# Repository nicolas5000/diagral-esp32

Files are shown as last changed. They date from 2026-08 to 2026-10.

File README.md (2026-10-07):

# diagral-uart-esp32
This project permits to connect to Diagral alarm system DIAG91AGFK using the 20 pins connector on the back (the connector used for the GSM board DIAG55AAX).

It permits to get status from and modify state of the alarm system as it could be done using call and SMS with official DIAG55AAX from Diagral, but using local MQTT connection... and it is directly recognized by Home Assistant!

This project is originally tested on XIAO-ESP32-S3 (with battery management by ESP32 board) and Waveshare ESP32-C6 (with battery management by the Diagral alarm system) hardware and based on ESP-IDF SDK version 6.0.2. It should also work with any other board compatible with Waveshare ESP32-S3 and ESP32-C6 board pinout.

This project is open source: you can reuse it and modify it, but please add a link to my project.
If you like this project you can [contribute](#how-to-contribute) or [buy me a coffee](https://buymeacoffee.com/nicolas5000) to support the tens of hours I spent on it :blush:.

### Why I did this project

From Diagral, DIAG55AAX (also known as DIAG55AAX1) is a 2G only mobile network board and DIAG55AAX5 is 2G/3G mobile network board. These boards will not work anymore in the future as the 2G and 3G mobile networks are being replaced by 4G and 5G networks. Of course you can buy the official Diagral 4G device to replace your old DIAG55AAX module.

The goal of this project is to connect your Diagral system locally to your Home Assistant without any Cloud based solution.

### **Disclaimer**  
> [!CAUTION]
> This tool is designed for educational and testing purposes, provided "as is", without warranty of any kind. It has no link with Diagral company. Creators and contributors are not responsible for any misuse or damage caused by this tool. Keep in mind that you should have a secure MQTT and Home Assistant instances to avoid any attack on your alarm system from your domotics.

### **Security**
To use this project in a secure way, you shall:
- Put the board on the back of the DIAG91AGFK so it is protected by your alarm system tamper mechanism.
- Put a password on command line access (at least in production, when not testing anymore).
- Use a secure network (Wifi password...).
- Use a secure MQTT connection (strong password, certificate...).
- Protect your Home Assistant access.
- If you want the best:
  - Sign your firmware and enable secure boot (see ESP-IDF documentation). This risk can be mitigated by using [HTTPS server for OTA update](#ota-over-https).
  - Enable flash encryption (see ESP-IDF documentation) to protect your Wifi password, command-line password and MQTT password. This risk is mitigated by putting the ESP32 on the back of the DIAG91AGFK (protected by your alarm system tamper mechanism).

### Documentation
This documentation contains useful information about the project, especially:
- [Hardware requirements](README.md#hardware-requirements) to use the project
- [Software configuration](doc/configuration.md) (hardware pins used, network and MQTT settings, ...)
- [Using command line](doc/command_line.md) to test and configure the project
- [MQTT topics and messages](doc/mqtt.md)
- [The project development](doc/development_guide.md) (structure of the project, how the source code is organized if you want to contribute or fork...)
- [The current knowledge about the protocol and commands](doc/protocol.md) used between DIAG91AGFK and DIAG55AAX

### Support
I try to give support on my free time. If you have questions you can open a subject and ask directly in English (for everyone to understand) or in French.

### Project status

These features are currently available:
- Get state from Diagral alarm system:
  - Mode (idle, setup, test)
  - Zones 1 to 4 status (disarmed, arming, armed, armed "home", triggered)
  - Battery charging state. Note: it works only if you have a battery connected to provide power to the device!
- Control the alarm system: Arm/"Arm home"/Disarm with or withour PIN code (choose before building firmware or from command line, can't be modified from MQTT and Home Assistant).
- Events:
  - Error event: event type (tamper, main power, battery, radio link, internet link, arm cancelled reason), harware type (system, sensor, command, siren), hardware number
  - Detection event: event type, sensor type, sensor number
  - Alert event: alert type (fire, alert, silent alert, duress disarm), command number
- Control the ESP32:
  - Reboot
  - Enable/disable logging
  - Enable/disable passive mode
- Connectivity:
  - Wifi (integrated to ESP32 chip) support
  - Ethernet support (based on W5500/WIZ850io module)
  - DHCP support, with DNS provided by DHCP server
  - Static IPv4 support, including manual DNS server configuration
- (S)NTP support for time synchronization (required to have valid timestamps in MQTT messages)
- Front-end:
  - Command line features: see [dedicated page](doc/command_line.md) for more information
    - Control the alarm system
    - Reboot ESP32
    - Change Wifi configuration without reflashing firmware (configuration applied after reboot)
    - Change DHCP/IPv4 configuration without reflashing firmware (configuration applied after reboot)
    - Change MQTT configuration without reflashing firmware (configuration applied after reboot)
    - Change Diagral configuration without reflashing firmware (configuration applied after reboot)
    - Note: command line features are password protected by default, change default password in project configuration before building firmware.
  - MQTT support: see [dedicated page](doc/mqtt.md) for more information
    - Discovery message is published and compatible with Home Assistant, permitting to automatically add device to it without extra configuration.
    - In addition:
      - A button is added to reboot the ESP32 board.
      - A switch is added to enable/disable Diagral layer logging (applied after reboot).
      - A switch is added to enable/disable Diagral passive mode (applied after reboot).
      - A text is added to provide URL of the new firmware for OTA (sending the text will start OTA).
- Configuration storage to flash
- [OTA firmware update](#ota-update) (update from Wifi or Ethernet using an HTTP(S) server) with rollback.
- MQTT connectivity watchdog: if MQTT connection is broken more than 5 minutes, the ESP32 will notify the alarm system and reboot.

### Diagral DIAG91AGFK 20-pins connector
The DIAG91AGFK has a 20-pins connector on the back to connect the DIAG55AAX GSM module. We use this connector for our project. Please check pin numbers:
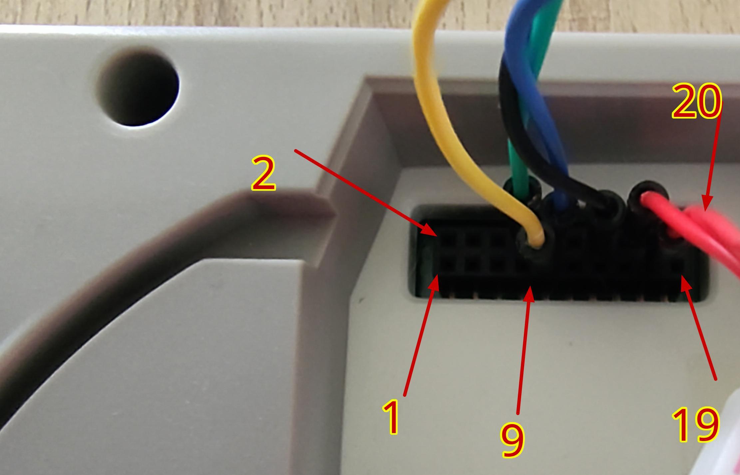
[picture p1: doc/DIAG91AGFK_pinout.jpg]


Here is the pin description for the connector:
| Pin # | Description | Used by the project? |
|----|---|---|
| 1 | Audio from DIAG91AGFK microphone, unknown format | No |
| 2 | Audio to DIAG91AGFK speaker, unknown format | No |
| 3 | Audio from DIAG91AGFK microphone, unknown format | No |
| 4 | Audio to DIAG91AGFK speaker, unknown format | No |
| 5 | GND | Yes (at least once) |
| 6 | GND | Yes (at least once) |
| 7 | Seems to be 2.8V (LVCMOS?) from DIAG91AGFK | No |
| 8 | RX for DIAG91AGFK / TX for DIAG55AAX and our project (0V at low state, 2.8V at high state) | Yes |
| 9 | "Signal" pin, low by default, set to 2.8V by DIAG91AGFK or DIAG55AAX a few ms before sending any command on corresponding TX (wake up?) | Yes |
| 10 | TX for DIAG91AGFK / RX for DIAG55AAX and our project (0V at low state, 2.8V at high state) | Yes |
| 11 | 3.3V from DIAG55AAX | No |
| 12 | Seems to be 2.8V (LVCMOS?) from DIAG91AGFK | No |
| 13 | GND | Yes (at least once) |
| 14 | GND | Yes (at least once) |
| 15 | GND | Yes (at least once) |
| 16 | Power from DIAG91AGFK | Yes (at least once) |
| 17 | +BATT from the project | Yes (at least once. If not using battery, use a 1N5819 to connect power from pin 16 or 18 to this pin) |
| 18 | Power from DIAG91AGFK | Yes (at least once) |
| 19 | +BATT from the project | Yes (at least once. If not using battery, use a 1N5819 to connect power from pin 16 or 18 to this pin) |
| 20 | +BATT from the project | Yes (at least once. If not using battery, use a 1N5819 to connect power from pin 16 or 18 to this pin) |

> [!NOTE]
> - It is not required to connect all GND pins as they are already connected together on DIAG91AGFK side. Connect your project board to at least 1 GND pin.
> - It is not required to connect all Power pins as they are already connected together on DIAG91AGFK side. Connect your project board to at least 1 power pin.
> - It is not required to connect all +BATT pins as they are already connected together on DIAG91AGFK side. Connect your project board to at least 1 +BATT pin.

### Hardware requirements
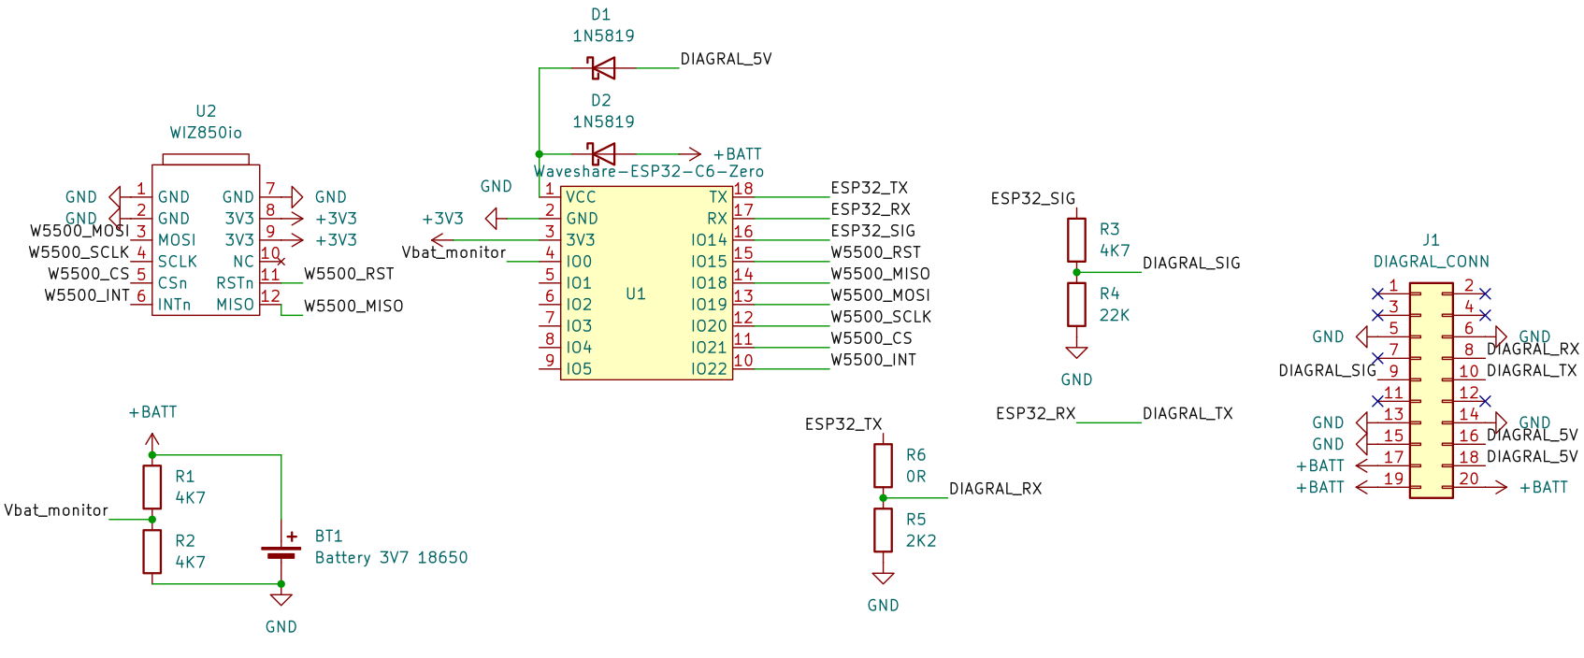
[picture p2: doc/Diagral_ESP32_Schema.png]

In order to use this project, you will need:
- ESP32 board:
  - For PCB "beta" and 1.0, use [Seeed Studio XIAO-ESP32-S3](https://www.amazon.fr/dp/B0BYSB66S5/).
  - For PCB 1.1, use Waveshare ESP32-C6 or ESP32-S3 (or from other provider, but with equivalent pinout).
- 5 or 6 resistors (see the schematics):
  - R1 and R2 are required only if you want to monitor battery voltage. You can choose any values but the voltage on the GPIO shall always remains under 3.3V! I chose to use the same resistors but it's not mandatory. You can modify min (0%) and max (100%) voltage values in the configuration.
  - R3 and R4 are always required as they permit to convert the voltage level between Diagral (2.8V) and ESP32 (3.3V) for "Signal" pin.
  - R5 and R6 are always required as they permit to convert the voltage level between Diagral (2.8V) and ESP32 (3.3V) for "ESP32 TX" pin. Please note that in my case R6 is not needed as the ESP32-S3 board from Seeed Studio and Waveshare already have a 499 ohm resistor internally.
- For PCB "beta" and 1.0, [XL74610](https://www.amazon.fr/dp/B0H2HY1DP9/) "ideal diode" if you plan to charge the battery from the DIAG91AGFK 5V power supply (in fact the DIAG91AGFK provides 4.5V and it is required to use at least 4.257V to fully charge a battery like 18650 that is 4.2V at 100%, so normal diode can't be used)
- 1 (PCB "beta" and 1.0) or 2 (PCB 1.1) 1N5819 diode(s).
- Wires:
  - To connect everything to the ESP32 board if you don't use a PCB.
  - To Replace R6 0 ohm resistor
  - On PCB "beta" and 1.0 only, to connect battery pins to XIAO back.
- USB cable to connect the ESP32 board to your computer for first flashing of the firmware.
- Battery (like 18650 battery, I didn't try to reuse the battery provided with the DIAG55AAX module but it could work) and its connector.
- [W5500](https://www.amazon.fr/dp/B0B775X737/) Ethernet module only if you don't want to use Wifi
- 20 pins connector to connect to DIAG91AGFK if you don't want to use "Dupont" wires on your final project board.

### PCB
I have created a [kicad](./kicad/) project for schematics and PCB routing. Current version of the PCB is 1.1.  
You can directly purchase a PCB (minimum order of 5 units) from PCBWay using this [link](https://www.pcbway.com/project/shareproject/diagral_esp32_gerber_d70e3251.html) or ask me for available PCB and passive components (I don't provide ESP32, W5500 and battery and I don't solder the components). 
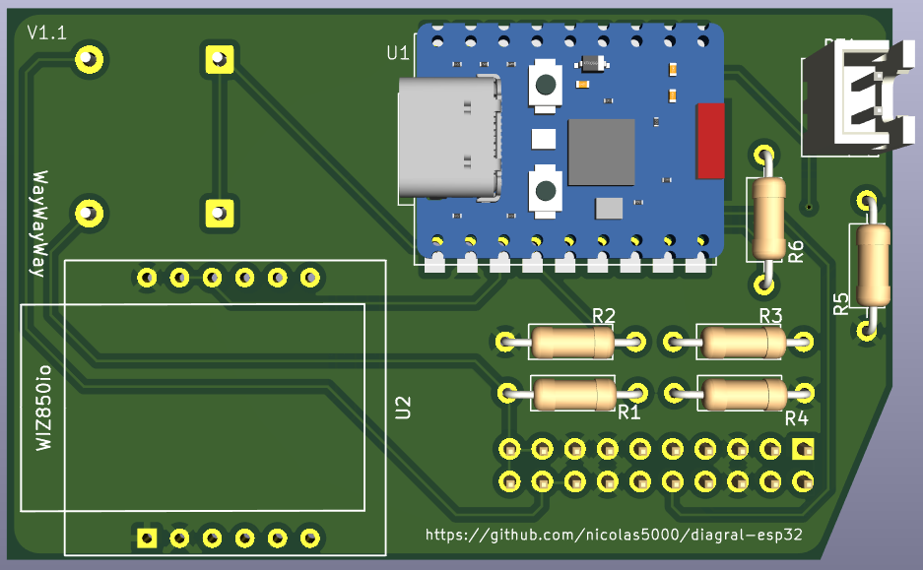
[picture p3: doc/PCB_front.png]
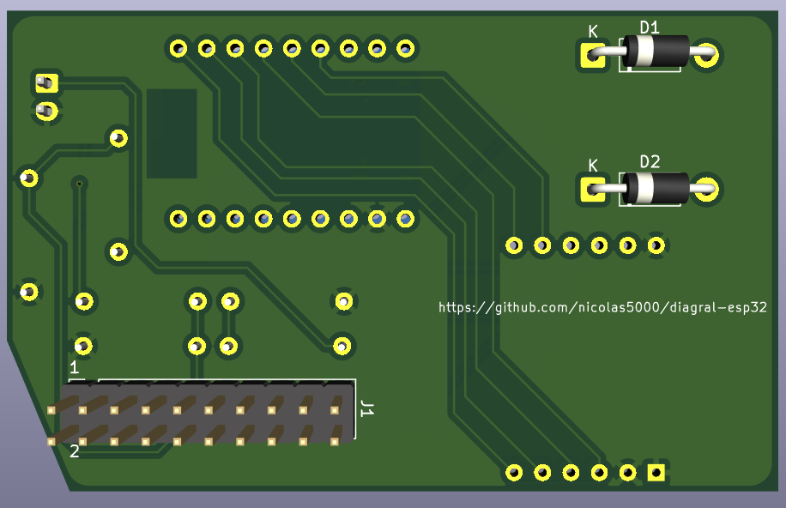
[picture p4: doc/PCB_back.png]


> [!CAUTION]
> Please note that mounting the W5500 module to use the Ethernet link will require to cut the back of the DIAG91AGFK because the W5500 is too big as you can see:
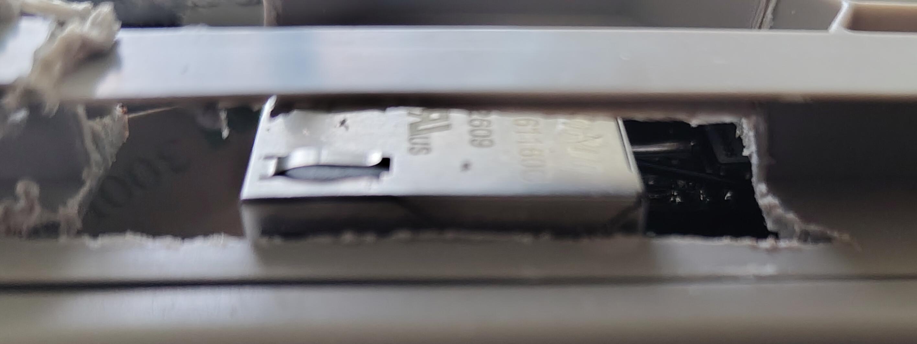
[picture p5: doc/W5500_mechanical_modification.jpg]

#### PCB versions

| PCB # | ESP32 compatibility | Limitations |
|----|---|---|
| beta | [Seeed Studio XIAO-ESP32-S3](https://www.amazon.fr/dp/B0BYSB66S5/) | (1) (2) |
| 1.0 | [Seeed Studio XIAO-ESP32-S3](https://www.amazon.fr/dp/B0BYSB66S5/) | (2) |
| 1.1 | Waveshare [ESP32-C6-Zero](https://amzn.eu/d/0iYieorw) or [ESP32-S3-Zero](https://amzn.eu/d/05cgIHxE) (or equivalent pinout and footprint) | No known limitation |

Known limitations:
- (1) Ethernet module is not working on this PCB due to footprint error. Use this PCB only for Wifi project.
- (2) The 1N5819 is missing on this PCB. You have to cut the track between R1 and pin 19 of the connector and put the 1N5819 as shown on the schematics below (D2):
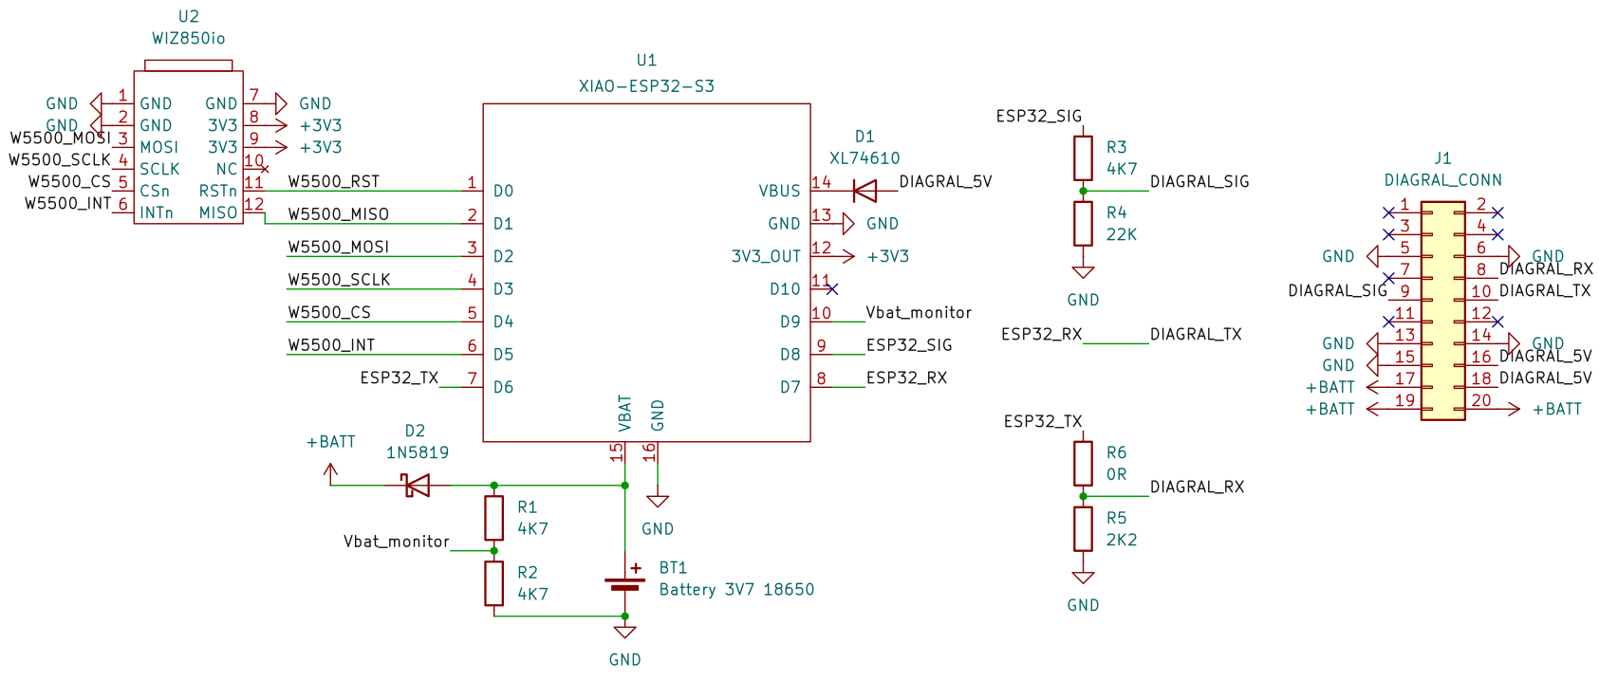
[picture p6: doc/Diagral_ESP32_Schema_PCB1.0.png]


#### Available PCB from France

| PCB # | PCB price | Passive components (optional) | Quantity available |
|----|---|---|---|
| beta | 3€ | 2€ for 20-pin connector, 1x 1N5819, 1x XL74610, 3x 4.7k resistors, 1x 22k resistor, 1x 2.2k resistor | 3 (in stock) |
| 1.0 | 3€ | 2€ for 20-pin connector, 1x 1N5819, 1x XL74610, 3x 4.7k resistors, 1x 22k resistor, 1x 2.2k resistor | 4 (in stock) |
| 1.1 | 5€ | 1€ for 20-pin connector, 2x 1N5819, 3x 4.7k resistors, 1x 22k resistor, 1x 2.2k resistor | on demand |

Additional costs for packaging and shipping to France (bubble envelope with tracking number) : 4€

> [!NOTE]
> Not included: ESP32, W5500 Ethernet module, battery and its connector, soldering the components on the PCB.

Here is an example of components on PCB 1.0:
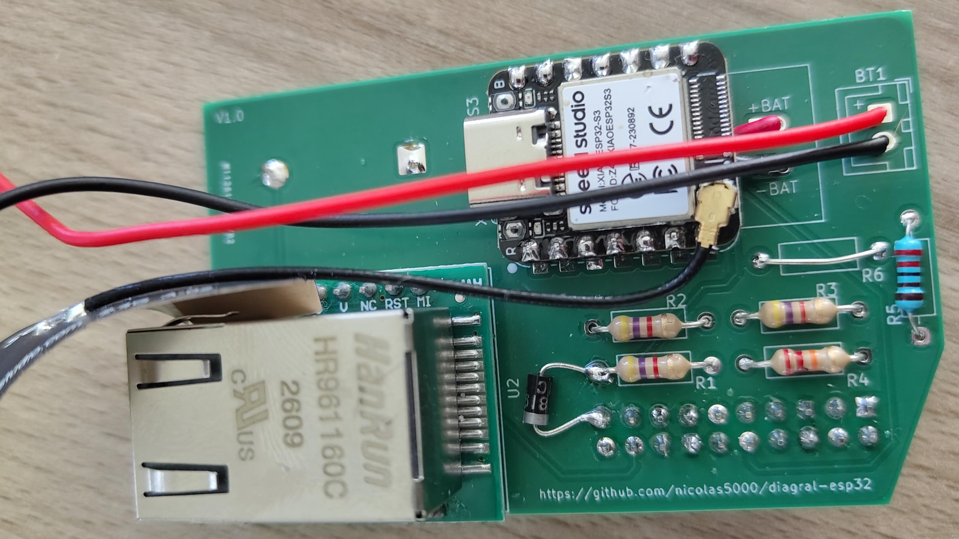
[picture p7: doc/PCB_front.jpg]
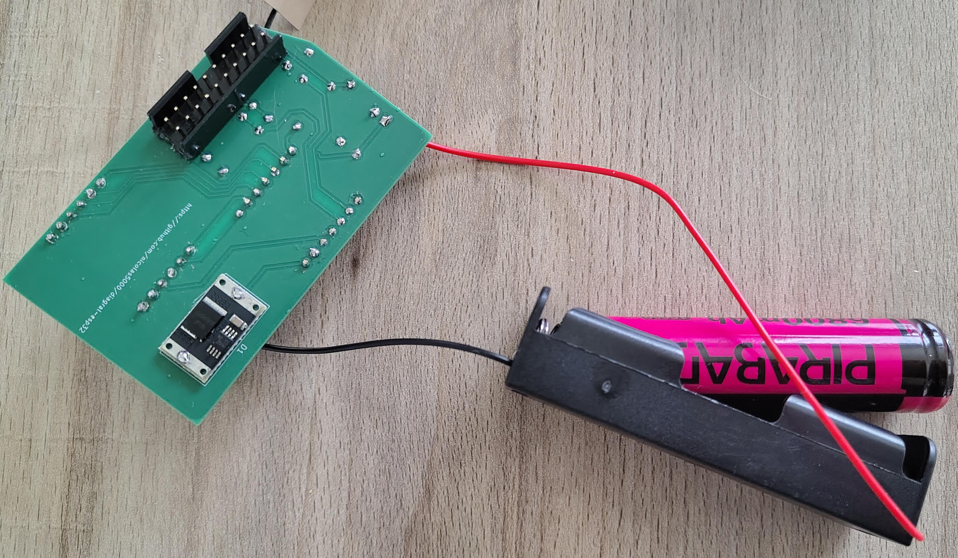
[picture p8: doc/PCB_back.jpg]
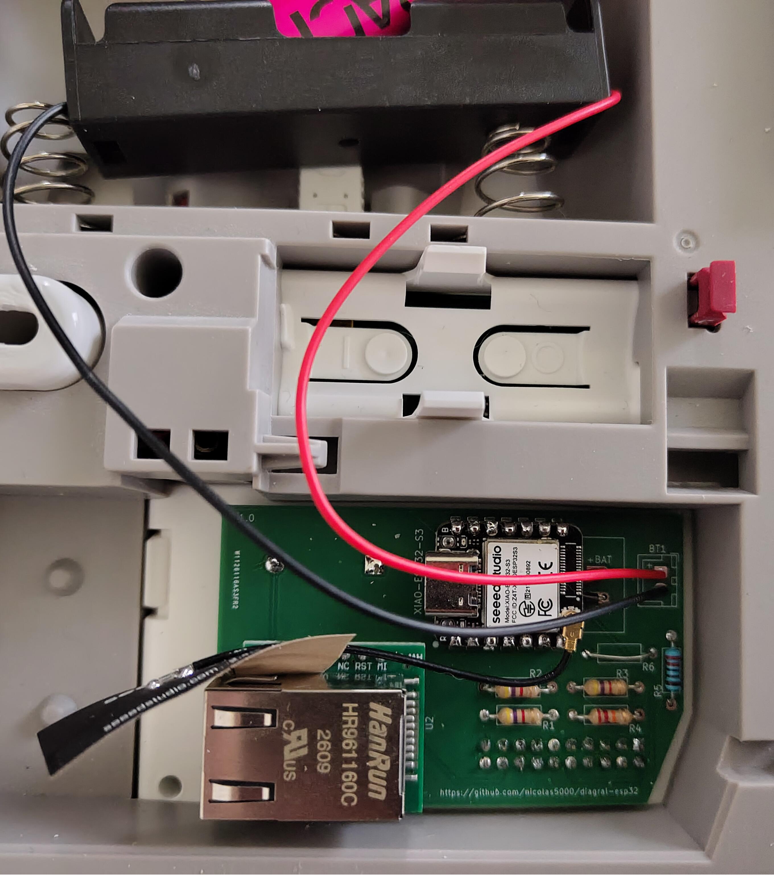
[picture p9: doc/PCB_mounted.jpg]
  

### Development environment

The development environment is based on:
- Visual Studio Code (also known as VSCode)
- ESP-IDF extension for VSCode and ESP-IDF SDK installed

### Starting guide

Here are a few steps to follow to start with this project:
1. If you are not familiar with VSCode and ESP-IDF, I encourage you to read ESP-IDF starting guide and try the "Hello world" example on your ESP32 board. You should be able to build the example, flash the binary to your ESP32 board and monitor the execution from ESP-IDF monitor tool before going to next step.
2. Download this project / clone the repository, then open the project folder in VSCode.
3. Solder the components on the PCB or use wires to connect all the pins on your prototyping board (see schematics above).
4. Copy and rename the sdkconfig.defaults_xxx file to sdkconfig.defaults depending on your hardware.
5. Choose the ESP32-S3 or ESP32-C6 target depending on your hardware.
6. Open "SDK Configuration Editor" to configure the project and go to "Diagral UART Project Configuration" section. Configure network and choose the GPIO pins you want to use to connect everything.
7. Provide your HTTPS public certificate for OTA (see [OTA section](#ota-update) to generate a certificate) or create an empty file named _ca_cert.pem_
8. Build the source code, flash it to the board and monitor (there is single button that does everything if you are confident, otherwise, use the 3 buttons in this order).

By default the project is configured with verbose enabled and not in passive mode: you can see what happens with detailed logs and you can control your Diagral alarm system. In active mode you can use the command line to send commands to your Diagral system. You can use passive mode to get frames from DIAG91AGFK to DIAG55AAX only (but you have to connect all 20 pins).

#### Passive mode

As previously explained, in passive mode (don't forget to enable verbose) you will get frames from DIAG91AGFK to DIAG55AAX only.
If you need to see all exchanges you will have to use another "spy UART project".

#### Active mode

In this mode you can control your alarm system.

> [!NOTE]
> Keep verbose enabled if you want to see what happens in Diagral UART layer. In addition to console, exchanged frames can be sent to a Syslog server.

### OTA update
In order to update the firmware from Wifi or Ethernet securely, you should use an HTTPS server. If you don't mind, you can also use a simple HTTP server. This section describes the 2 options.

> [!NOTE]
> After OTA is performed, the ESP32 will reboot automatically. Then, if MQTT is not able to connect within 60s, the rollback will be performed to reboot on previous firmware.

#### OTA over HTTPS
1. Generate your certificate and key: you can use the command `openssl req -x509 -newkey rsa:2048 -keyout ca_key.pem -out ca_cert.pem -days 365 -nodes`. Don't forget to use a CN field that matches the machine IP address or name (like _myserver.lan_) that will be used in the URL when performing OTA. Note: this file is required to build and be included within the first firmware to load using USB.
2. Open the update port in your firewall
3. Launch the HTTPS server. You can use the command `python3 simple_ota_https_server.py <BIN_DIR> <PORT> [CERT_DIR]` (simple_ota_https_server.py is in the tools folder)
4. From Home Assistant, enter the URL of the .bin file: `https://myserver.lan:8070/diagral-uart-esp32.bin` assuming you are using port 8070 on machine myserver.lan
5. Wait a few time (upgrade should be done in less than 30 seconds)

#### OTA over HTTP
1. Create an empty file named ca_cert.pem and disable option _Allow OTA update only over HTTPS_ in the project configuration before building the firmware
2. Open the update port in your firewall
3. Launch the HTTP server. You can use the command `python3 -m http.server 8070 --bind ::` in the build folder containing diagral-uart-esp32.bin
4. From Home Assistant, enter the URL of the .bin file: `http://myserver.lan:8070/diagral-uart-esp32.bin` assuming you are using port 8070 on machine myserver.lan
5. Wait a few time (upgrade should be done in less than 30 seconds)

### Home Assistant integration
The board will be automatically discovered by Home Assistant MQTT integration and provide controls (with control panel for all zones and for each zone), PIN code verification (if enabled in the configuration), events (detection, alert, error), diagnostics and OTA firmware update.
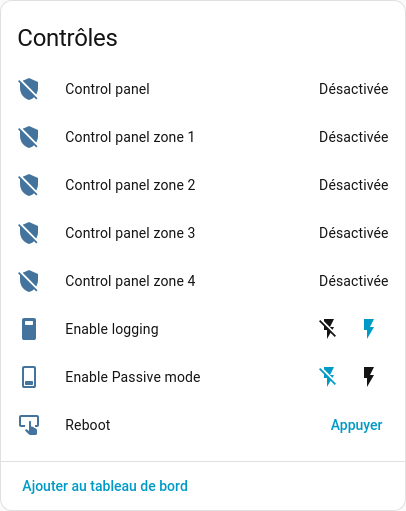
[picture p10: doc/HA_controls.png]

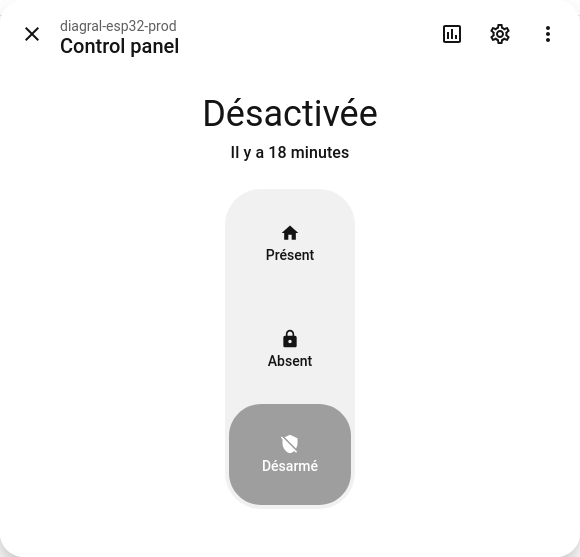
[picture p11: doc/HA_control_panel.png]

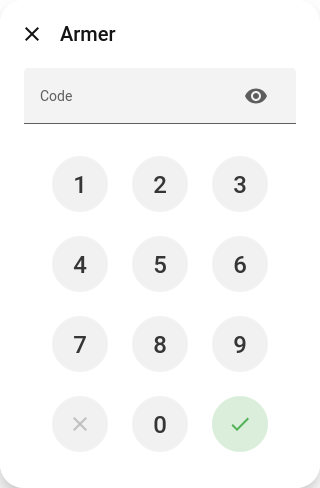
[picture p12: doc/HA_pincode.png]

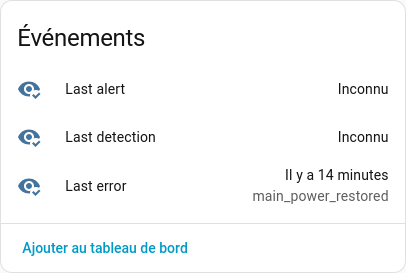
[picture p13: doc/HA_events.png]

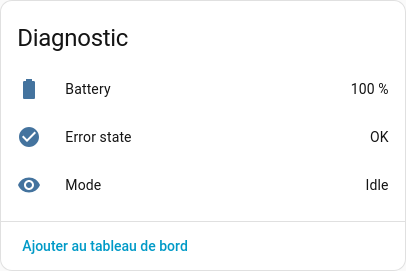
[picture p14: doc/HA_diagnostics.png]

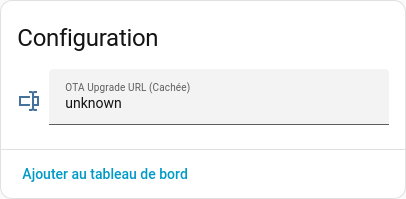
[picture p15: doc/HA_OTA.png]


### How to contribute

You can mainly contribute to this project by:
- Testing this project on your DIAG91AGFK alarm system and reporting any issue.
- If you have development skills you can propose source code modification to fix issues.
- [Buy me a coffee](https://buymeacoffee.com/nicolas5000).

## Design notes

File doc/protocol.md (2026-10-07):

# Communication protocol between DIAG91AGFK alarm system and DIAG55AAX GSM module
This page describes most of the protocol used between DIAG91AGFK alarm system and DIAG55AAX GSM module... at least useful commands to control and monitor the alarm system from this UART link.

## Hardware

### Pinout
As described in [Diagral DIAG91AGFK 20-pins connector](../README.md#diagral-diag91agfk-20-pins-connector), the 3 pins to control and monitor the alarm system are:
- Pin 8: UART RX for DIAG91AGFK / TX for DIAG55AAX
- Pin 9: "Signal" pin, low by default, set to 2.8V by DIAG91AGFK or DIAG55AAX a few ms before sending any command on corresponding TX (wake up?)
- Pin 10: UART TX for DIAG91AGFK / RX for DIAG55AAX

### UART
The UART characteritics are 115200 bps, 8 bits of data, no parity bit, 1 stop bit.

## Protocol

### Frame format

The format of each frame is:
| Byte # | Description |
|----|---|
| 0 | L = Length of the frame (this byte excluded) |
| 1 | Frame counter, from 0x00 to 0xFF, independent and incremented by each side (one for DIAG91AGFK, one for DIAG55AAX/ESP32) |
| 2 | I = Identifier of the frame |
| ... | ... |
| L | Checksum (XOR of all previous bytes, byte 0 included) |

> [!NOTE]
> In the following of this document, the frame length (byte 0), frame counter (byte 1) and checksum (last byte) will not always be shown for easy reading, however they are always present in the frames.

### Frame description

#### I=0x40 - ACK
All frames sent from one side must be acknowledged by the other side by sending this frame:
| Byte # | Description |
|----|---|
| 0 | L = Length of the frame (this byte excluded) = 0x04 |
| 1 | Frame counter of the frame to acknowledge |
| 2 | I = 0x40 |
| 3 | 0x01 (OK) |
| 4 | Checksum (XOR of all previous bytes, byte 0 included) |

#### I=0x04 - Commands to manage audio or binary blobs
> [!NOTE]
> This project doesn't use these audio or binary blobs, however we need to at least reply correctly to the frames from the alarm system.

| Byte # | Description |
|----|---|
| 0 | L = Length of the frame (this byte excluded) |
| 1 | Frame counter |
| 2 | I = Identifier of the frame |
| 3 | Always 0x20 |
| 4 | J Sub-command (see below) |
| ... | ... |
| L | Checksum (XOR of all previous bytes, byte 0 included) |

##### J=0x01 - Description of an audio or binary blob
This frame is used to describe an audio or binary blob, before transmitting the fragments.
| Byte # | Description |
|----|---|
| 2 | I = 0x04 |
| 3 | Always 0x20 |
| 4 | J = 0x01 |
| 5-11 | TBD |
| 12-13 | Total length of the audio or binary blob in bytes, MSB first |
| 14-15 | Maximum supported length of a segment in bytes, MSB first |

##### J=0x02 - Length of a segment (response to J=0x01)
This frame is a response to [J=0x01](#j0x01---description-of-an-audio-or-binary-blob), it contains the maximum supported length of a segment from the other side.
| Byte # | Description |
|----|---|
| 2 | I = 0x04 |
| 3 | Always 0x20 |
| 4 | J = 0x02 |
| 5-6 | Maximum supported length of a segment in bytes, MSB first |
| 7 | 0x00 - Only sent by the GSM module to accept the [J=0x01](#j0x01---description-of-an-audio-or-binary-blob) command to write the blob |

##### J=0x03 - Transmission of a fragment
This frame permits to transmit a fragment of a blob (part of the welcome message, personalized message for a sensor, ...)
| Byte # | Description |
|----|---|
| 2 | I = 0x04 |
| 3 | Always 0x20 |
| 4 | J = 0x03 |
| 5-6 | Fragment #, MSB first, strating from 1 |
| 7-8 | L = Length of the segment in bytes, MSB first |
| ... | Value (L bytes) |

##### J=0x04 - End of transmission of an audio or binary blob (after last J=0x03)
After sending all the fragments with [J=0x03](#j0x03---transmission-of-a-fragment), the sender emits this frame.
| Byte # | Description |
|----|---|
| 2 | I = 0x04 |
| 3 | Always 0x20 |
| 4 | J = 0x04 |

##### J=0x08 - Request to send an audio or binary blob
This frame is sent by the alarm system to the GSM module to read / extract a blob.
| Byte # | Description |
|----|---|
| 2 | I = 0x04 |
| 3 | Always 0x20 |
| 4 | J = 0x08 |
| 5-10 | TBD, same bytes as bytes 5-10 from [J=0x01](#j0x01---description-of-an-audio-or-binary-blob) |

##### J=0x09 - ACK of a segment (response to J=0x03)
This frame is sent to acknowldge each [fragment received](#j0x03---transmission-of-a-fragment).
| Byte # | Description |
|----|---|
| 2 | I = 0x04 |
| 3 | Always 0x20 |
| 4 | J = 0x09 |
| 5-6 | fragment # to acknowledge |

#### I=0x07 - Main commands
This section contains all the other commands to control and get status and notifications from the alarm system.
| Byte # | Description |
|----|---|
| 0 | L = Length of the frame (this byte excluded) |
| 1 | Frame counter |
| 2 | I = 0x07 |
| 3 | J Sub-command (see below) |
| ... | ... |

##### J=0x60 - Command to change the alarm system state
This frame is sent by the GSM module to get or change the alarm system state. The request contains 11 data bytes, so byte 0 (L) is 0x0D.
| Byte # | Description |
|----|---|
| 2 | I = 0x07 |
| 3 | J = 0x60 |
| 4 | 0x00 |
| 5 | Operation code (see below) |
| 6-12 | Reserved bytes and zone masks, depending on the operation |

The operation codes are:
| Value | Operation | Zone bytes |
|----|----|----|
| 0x10 | Disarm all zones | Bytes 6-7 = 0xFF |
| 0x11 | Arm all zones | Bytes 8-9 = 0xFF |
| 0x12 | Arm or disarm selected zones | Byte 7 = zones to disarm; byte 9 = zones to arm |
| 0x13 | Arm the home zones | No zone mask |
| 0x30 | Get the current state | No zone mask |

Zone masks use one bit per zone: 0x01 = zone 1, 0x02 = zone 2, 0x04 = zone 3, and 0x08 = zone 4. 0xFF can be used to select all zones.

A successful command is normally acknowledged with a miscellaneous response (K=0x28) and a status of 0x01. After that, the alarm system then returns a [J=0x62 status notification](#j0x62---status-notification-from-the-alarm-system), or refuses the change with [K=0x49](#k0x49---state-change-refused).
##### J=0x62 - Status notification from the alarm system
This notification is sent by the alarm system when its state changes. It can also be returned in response to a [J=0x60 state request](#j0x60---command-to-change-the-alarm-system-state). The payload contains 18 data bytes, so byte 0 (L) is 0x12.
| Byte # | Description |
|----|---|
| 2 | I = 0x07 |
| 3 | J = 0x62 |
| 4 | System mode: 0x00 = idle, 0x40 = test, 0x80 = setup |
| 5 | State flags (see below) |
| 6 | Error flags (see below) |
| 7 | Not interpreted by this project |
| 8 | Zone mask used when the system is disarmed |
| 9 | Not interpreted by this project |
| 10 | Zone mask used when the system is armed or arming |
| 11-17 | Not interpreted by this project |

The state flags in byte 5 use the following bits:
| Bit | Value | Meaning |
|----|----|----|
| 0 | 0x01 | Response to a state request |
| 1 | 0x02 | Home mode is active |
| 4 | 0x10 | Partial arm is active |
| 6 | 0x40 | Full arm is active |
| 7 | 0x80 | The system is arming |

The error flags in byte 6 can have the following values:
| Value | Meaning |
|----|----|
| 0x02 | Error (power lost, tamper, radio...) |
| 0x21 | Arm cancelled due to open issue |
| 0x22 | Arm cancelled due to transmitter error |
| 0x23 | Arm cancelled due to tamper |

The zone masks in bytes 8 and 10 use the same bit assignment as the [J=0x60 command](#j0x60---command-to-change-the-alarm-system-state).
##### J=0x65 - Alert notification from the alarm system
This notification is sent by the alarm system when an alert is triggered. The payload contains 13 data bytes, so byte 0 (L) is 0x0D.
| Byte # | Description |
|----|---|
| 2 | I = 0x07 |
| 3 | J = 0x65 |
| 4 | Not interpreted by this project |
| 5 | Alert type: 0x40 = fire, 0x50 = alert, 0x51 = silent alert, 0x53 = duress disarm alert |
| 6-8 | Not interpreted by this project |
| 9 | Number of the command that triggered the alert |
| 10+ | Not interpreted by this project |

The ESP32 records the alert type, command number, and reception time. No application-level response is required; the frame is acknowledged at the protocol link layer.
##### J=0x68 - Detection notification from the alarm system
This notification is sent by the alarm system when a sensor event occurs. The payload contains 13 data bytes, so byte 0 (L) is 0x0D.
| Byte # | Description |
|----|---|
| 2 | I = 0x07 |
| 3 | J = 0x68 |
| 4 | Not interpreted by this project |
| 5 | Detection event type (see below) |
| 6 | Zone mask for the affected zones |
| 7-9 | Not interpreted by this project |
| 10 | Sensor type: 0x00 = timeout, 0x01 = movement, 0x02 = opening |
| 11 | Sensor number |
| 12+ | Not interpreted by this project |

The known event types are:
| Value | Event |
|----|----|
| 0x07 | Dissuasion |
| 0x08 | Pre-alarm |
| 0x09 | Caution |
| 0x0A | Intrusion |
| 0x0B | Timer started |
| 0x0C | Timer ended |
| 0x18 | Pre-alarm confirmed |
| 0x1A | Intrusion confirmed |

The zone mask uses bit 0 for zone 1, bit 1 for zone 2, bit 2 for zone 3, and bit 3 for zone 4. The ESP32 marks the corresponding zones as triggered and records the event type, sensor type, sensor number, and reception time.
##### J=0x69 - GSM connectivity notification
This frame is sent by the GSM module to notify connectivity status. The payload contains 6 data bytes, so byte 0 (L) is 0x06.
| Byte # | Description |
|----|---|
| 2 | I = 0x07 |
| 3 | J = 0x69 |
| 4 | 0x01 in case of connectivity error, 0x00 otherwise |
| 5 | 0x55 = Connectivity status |
##### J=0x6B - Error notification from the alarm system
This notification is sent by the alarm system when an error or fault is raised or cleared. The payload contains 12 data bytes, so byte 0 (L) is 0x0C.
| Byte # | Description |
|----|---|
| 2 | I = 0x07 |
| 3 | J = 0x6B |
| 4 | System mode: 0x00 = idle, 0x40 = test, 0x80 = setup |
| 5 | Error state: 0x00 = cleared/restored, non-zero = active |
| 6 | Error type (see below) |
| 7 | Hardware type (see below) |
| 8 | Not interpreted by this project, seems to be always 0x00 |
| 9 | Hardware number |
| 10 | Not interpreted by this project, seems to be always 0x00 |
| 11 | Zone the sensor is part of, if error type is 'Radio link lost' and hardware type is 'sensor' |

The known error types are:
| Value | Meaning when active | Meaning when byte 5 is 0x00 |
|----|----|----|
| 0x40 | Tamper active | Tamper cleared |
| 0x55 | GSM or Internet link lost | GSM or Internet link restored |
| 0x59 | Radio link lost | Radio link restored |
| 0x70 | Battery low | Battery restored |
| 0x71 | GSM battery low | GSM battery restored |

The known hardware types are:
| Value | Hardware |
|----|----|
| 0x10 or 0x14 | Alarm system |
| 0x20 | Command module |
| 0x30 or 0x31 | Sensor |
| 0x40 | Siren |
| 0x50 | Internet transmitter |

The ESP32 records the error state, hardware type, hardware number, and reception time. Main power events are reported separately with [K=0x42](#k0x42---alarm-system-power-notification).
##### J=0x6C - State change ack
This frame is sent by the GSM module when the alarm system mode changes (in response to [J=0x62](#j0x62---status-notification-from-the-alarm-system)). The payload contains 6 data bytes, so byte 0 (L) is 0x06.
| Byte # | Description |
|----|---|
| 2 | I = 0x07 |
| 3 | J = 0x6C |
| 4 | 0x80 if alarm system in idle mode, 0x00 otherwise |
| 5 | 0x00 Unknown |
##### J=0x71 - PIN code management
This command family is used to read the configured PIN length and check a PIN code before sending a state-changing command.
###### K=0x09 - Request for PIN code length
This frame is sent by the GSM module to request the length of the PIN code.
| Byte # | Description |
|----|---|
| 2 | I = 0x07 |
| 3 | J = 0x71 |
| 4 | K = 0x09 |
###### K=0x0A - PIN code length response
This frame is returned by the alarm system in response to K=0x09.
| Byte # | Description |
|----|---|
| 2 | I = 0x07 |
| 3 | J = 0x71 |
| 4 | K = 0x0A |
| 5 | PIN code length in digits |
###### K=0x0B - Request for PIN code check
This frame is sent by the GSM module to check a PIN code. The PIN is encoded as BCD, with two decimal digits per byte and the first digit in the high nibble. The protocol supports up to six digits and pads an unused final byte with 0x00.
| Byte # | Description |
|----|---|
| 2 | I = 0x07 |
| 3 | J = 0x71 |
| 4 | K = 0x0B |
| 5 | PIN digits 1 and 2 |
| 6 | PIN digits 3 and 4 |
| 7 | PIN digits 5 and 6 |

For example, PIN `1234` is encoded as `0x12 0x34 0x00`. The input must contain decimal digits only.
###### K=0x0C - PIN code check status
This frame is returned by the alarm system in response to K=0x0B.
| Byte # | Description |
|----|---|
| 2 | I = 0x07 |
| 3 | J = 0x71 |
| 4 | K = 0x0C |
| 5 | 0x00 = PIN accepted; any other value = PIN rejected |
##### J=0x95 - Unknown from alarm system
This frame is sent by the alarm system during startup or power-on. Its payload is not interpreted by this project, but the frame requires a response from the GSM module.
| Byte # | Description |
|----|---|
| 2 | I = 0x07 |
| 3 | J = 0x95 |
| 4+ | Startup or power-on payload, not decoded |
##### J=0x96 - Unknown from GSM module
This is the response sent by the GSM module to a [J=0x95 frame](#j0x95---unknown-from-alarm-system). The following payload is an observed response that is reused in this project; the meaning of its individual bytes has not been determined.
| Byte # | Description |
|----|---|
| 2 | I = 0x07 |
| 3 | J = 0x96 |
| 4 | 0x81 |
| 5 | 0x02 |
| 6 | 0x0A |
| 7 | 0x26 |
| 8 | 0x6E |
| 9 | 0x24 |
| 10 | 0x01 |
| 11 | 0x90 |
| 12 | 0x31 |
| 13 | 0x01 |
| 14 | 0x01 |
| 15 | 0x00 |
| 16 | 0x00 |
##### J=0xB0 - Misc commands
This section contains miscellaneous commands and notifications.
###### K=0x10 - Language
This notification is sent by the alarm system to report its language.
| Byte # | Description |
|----|---|
| 2 | I = 0x07 |
| 3 | J = 0xB0 |
| 4 | K = 0x10 |
| 5 | Not interpreted by this project |
| 6 | Language code: 0x00 = French, 0x01 = Italian, 0x02 = German, 0x03 = Spanish, 0x04 = Dutch, 0x05 = English |
###### K=0x28 - Command validation response
This frame is sent by the alarm system or by the GSM module in response to some commands to be validated.
| Byte # | Description |
|----|---|
| 2 | I = 0x07 |
| 3 | J = 0xB0 |
| 4 | K = 0x28 |
| 5 | status: 0x00 = unknown parameter, 0x01 = OK, 0x02 = error |
###### K=0x40 - Unknown from alarm system
This frame is sent by the alarm system during initialization. Its payload is not interpreted by this project, but the frame requires a response from the GSM module.
| Byte # | Description |
|----|---|
| 2 | I = 0x07 |
| 3 | J = 0xB0 |
| 4 | K = 0x40 |
###### K=0x41 - Unknown from GSM module
This is the response sent by the GSM module to [K=0x40](#k0x40---unknown-from-alarm-system).
| Byte # | Description |
|----|---|
| 2 | I = 0x07 |
| 3 | J = 0xB0 |
| 4 | K = 0x41 |
| 5 | 0x00 |
###### K=0x42 - Alarm system power notification
This notification is sent by the alarm system to report a change in its power or battery state.
| Byte # | Description |
|----|---|
| 2 | I = 0x07 |
| 3 | J = 0xB0 |
| 4 | K = 0x42 |
| 5 | Power state: 0x00 or 0x02 = main power lost, 0x01 = main power restored, 0x03 = battery low |
| 6+ | Not interpreted by this project |

The controller records the event as a system error with hardware number 0. Other power-state values are treated as unknown.
###### K=0x49 - State change refused
This frame is sent in response to [J=0x60](#j0x60---command-to-change-the-alarm-system-state) to refuse to change the state, mainly due to errors (tamper...) or open doors/windows.
| Byte # | Description |
|----|---|
| 2 | I = 0x07 |
| 3 | J = 0xB0 |
| 4 | K = 0x49 |
| 5 | 0x03 = refused to change alarm system state |

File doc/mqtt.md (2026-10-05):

# MQTT interface

## Configuration

See [Project configuration](configuration.md#mqtt-configuration-parameters) and [Command line configuration](command_line.md#configure-mqtt-client) to configure MQTT client, discovery prefix and topic prefix.

## Discovery

Discovery is compatible with Home Assistant discovery, that automatically adds devices to Home Assistant without any manual configuration from user.
See [Home Assistant MQTT discovery](https://www.home-assistant.io/integrations/mqtt/#mqtt-discovery) for more details.

### Controller discovery

Main features provided by the ESP32 are exposed to _MQTT_DISCOVERY_PREFIX/config_
By default, _MQTT_DISCOVERY_PREFIX_ is equal to _homeassistant/device/diagral-uart_, so complete path is _homeassistant/device/diagral-uart/config_

Discovery message exposes controller description and mandatory fields required by Home Assistant. In addition, it also exposes some features and configuration parameters like:
- Diagral logging configuration (change is applied after reboot)
- Diagral passive mode configuration (change is applied after reboot)
- _Reboot_ button: this button orders an immediate soft reboot of the controller
- _OTA Upgrade URL_ text: this input can be used to send an OTA update request by providing the URL of the .bin file

Here is an example of discovery message sent to this topic:
```
{
	"dev":	{
		"ids":	"diagral-esp32",
		"name":	"diagral-esp32",
		"mf":	"nicolas5000",
		"sw":	"1"
	},
	"o":	{
		"name":	"diagral-esp32",
		"url":	"https://github.com/nicolas5000/diagral-esp32",
		"sw":	"1"
	},
	"availability_topic":	"diagral-esp32/status",
	"cmps":	{
		"reboot":	{
			"p":	"button",
			"unique_id":	"diagral-esp32_button_reboot",
			"name":	"Reboot",
			"command_topic":	"diagral-esp32/button_reboot/set"
		},
		"upgrade":	{
			"p":	"text",
			"unique_id":	"diagral-esp32_ota_upgrade",
			"name":	"OTA Upgrade URL",
			"entity_category":	"config",
			"visible_by_default":	false,
			"command_topic":	"diagral-esp32/ota_upgrade/set",
			"command_template":	"{\"url\": \"{{ value }}\"}"
		},
		"Logging":	{
			"p":	"switch",
			"unique_id":	"diagral-esp32_Logging",
			"name":	"Enable logging",
			"optimistic":	true,
			"state_topic":	"diagral-esp32/config/state",
			"value_template":	"{{ value_json.Logging }}",
			"command_topic":	"diagral-esp32/config/set",
			"command_template":	"{\"Logging\": \"{{ value }}\"}"
		},
		"Passive":	{
			"p":	"switch",
			"unique_id":	"diagral-esp32_Passive",
			"name":	"Enable Passive mode",
			"optimistic":	true,
			"state_topic":	"diagral-esp32/config/state",
			"value_template":	"{{ value_json.Passive }}",
			"command_topic":	"diagral-esp32/config/set",
			"command_template":	"{\"Passive\": \"{{ value }}\"}"
		},
		"error":	{
			"p":	"binary_sensor",
			"unique_id":	"diagral-esp32_error",
			"name":	"Error state",
			"entity_category":	"diagnostic",
			"device_class":	"problem",
			"state_topic":	"diagral-esp32/info",
			"value_template":	"{{ value_json.error }}"
		},
		"mode":	{
			"p":	"sensor",
			"unique_id":	"diagral-esp32_mode",
			"name":	"Mode",
			"entity_category":	"diagnostic",
			"state_topic":	"diagral-esp32/info",
			"value_template":	"{{ value_json.mode }}"
		},
		"battery":	{
			"p":	"sensor",
			"unique_id":	"diagral-esp32_battery",
			"name":	"Battery",
			"entity_category":	"diagnostic",
			"device_class":	"battery",
			"unit_of_measurement":	"%",
			"state_topic":	"diagral-esp32/info",
			"value_template":	"{{ value_json.battery }}"
		},
		"panel":	{
			"p":	"alarm_control_panel",
			"unique_id":	"diagral-esp32_alarm_control_panel",
			"name":	"Control panel",
			"command_topic":	"diagral-esp32/control_panel/set",
			"command_template":	"{\"action\": \"{{ action }}\", \"code\": \"{{ code }}\", \"zones\": 15 }",
			"state_topic":	"diagral-esp32/control_panel/state",
			"value_template":	"{{ value_json.all }}",
			"code_arm_required":	true,
			"code_disarm_required":	true,
			"code":	"REMOTE_CODE",
			"supported_features":	["arm_home", "arm_away"]
		},
		"zone1":	{
			"p":	"alarm_control_panel",
			"unique_id":	"diagral-esp32_alarm_control_panel_zone1",
			"name":	"Control panel zone 1",
			"command_topic":	"diagral-esp32/control_panel/set",
			"command_template":	"{\"action\": \"{{ action }}\", \"code\": \"{{ code }}\", \"zones\": 1 }",
			"state_topic":	"diagral-esp32/control_panel/state",
			"value_template":	"{{ value_json.zone1 }}",
			"code_arm_required":	true,
			"code_disarm_required":	true,
			"code":	"REMOTE_CODE",
			"supported_features":	["arm_away"]
		},
		"zone2":	{
			"p":	"alarm_control_panel",
			"unique_id":	"diagral-esp32_alarm_control_panel_zone2",
			"name":	"Control panel zone 2",
			"command_topic":	"diagral-esp32/control_panel/set",
			"command_template":	"{\"action\": \"{{ action }}\", \"code\": \"{{ code }}\", \"zones\": 2 }",
			"state_topic":	"diagral-esp32/control_panel/state",
			"value_template":	"{{ value_json.zone2 }}",
			"code_arm_required":	true,
			"code_disarm_required":	true,
			"code":	"REMOTE_CODE",
			"supported_features":	["arm_away"]
		},
		"zone3":	{
			"p":	"alarm_control_panel",
			"unique_id":	"diagral-esp32_alarm_control_panel_zone3",
			"name":	"Control panel zone 3",
			"command_topic":	"diagral-esp32/control_panel/set",
			"command_template":	"{\"action\": \"{{ action }}\", \"code\": \"{{ code }}\", \"zones\": 4 }",
			"state_topic":	"diagral-esp32/control_panel/state",
			"value_template":	"{{ value_json.zone3 }}",
			"code_arm_required":	true,
			"code_disarm_required":	true,
			"code":	"REMOTE_CODE",
			"supported_features":	["arm_away"]
		},
		"zone4":	{
			"p":	"alarm_control_panel",
			"unique_id":	"diagral-esp32_alarm_control_panel_zone4",
			"name":	"Control panel zone 4",
			"command_topic":	"diagral-esp32/control_panel/set",
			"command_template":	"{\"action\": \"{{ action }}\", \"code\": \"{{ code }}\", \"zones\": 8 }",
			"state_topic":	"diagral-esp32/control_panel/state",
			"value_template":	"{{ value_json.zone4 }}",
			"code_arm_required":	true,
			"code_disarm_required":	true,
			"code":	"REMOTE_CODE",
			"supported_features":	["arm_away"]
		},
		"last_detection":	{
			"p":	"event",
			"unique_id":	"diagral-esp32_last_detection",
			"name":	"Last detection",
			"event_types":	["dissuasion", "pre_alarm", "caution", "intrusion", "timer_start", "timer_end", "pre_alarm_confirmed", "intrusion_confirmed"],
			"state_topic":	"diagral-esp32/last_detection"
		},
		"last_alert":	{
			"p":	"event",
			"unique_id":	"diagral-esp32_last_alert",
			"name":	"Last alert",
			"event_types":	["alert", "fire", "silent", "duress_disarm"],
			"state_topic":	"diagral-esp32/last_alert"
		},
		"last_error":	{
			"p":	"event",
			"unique_id":	"diagral-esp32_last_error",
			"name":	"Last error",
			"event_types":	["tamper", "tamper_clear", "main_power_lost", "main_power_restored", "battery_low", "battery_restored", "radio_lost", "radio_restored", "link_lost", "link_restored", "arm_cancel_issue_open", "arm_cancel_transmitter_error", "arm_cancel_tamper"],
			"state_topic":	"diagral-esp32/last_error"
		}
	}
}

```

## Topics and payloads

All topics are prefixed by _MQTT_TOPIC_PREFIX_, that is by default _diagral-uart_  
All topics and payloads are described in discovery messages and compatible with Home Assistant, so they will not be described here. See [Home Assistant MQTT documentation](https://www.home-assistant.io/integrations/mqtt/) for more details.

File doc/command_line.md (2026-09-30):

# Command line usage

> [!NOTE]
> By default command line is protected by a password, see [configuration](doc/configuration.md#main-parameters) to change this password.

## Help

After login to command line, you can access different commands explained below.
The command `help` permits to display all commands available in running firmware.
```
help  [<string>] [-v <0|1>]
  Print the summary of all registered commands if no arguments are given,
  otherwise print summary of given command.
      <string>  Name of command
  -v, --verbose=<0|1>  If specified, list console commands with given verbose level
```

## Misc commands

### Reboot
```
reboot 
  Reboot ESP32
```
### Logout
```
logout 
  Logout from ESP32 console
```

## Configuration commands

### Configure command line password
```
config_password  [-d] [--pass=<password>]
  Configure console password (change is applied immediately)
  -d, --delete  Delete current configuration in storage (no other argument required)
  --pass=<password>  Password (up to 32 characters)
```

### Configure Wifi
```
config_wifi  [-rd] [--ssid=<SSID>] [--pwd=<password>] [--saemode=<SAE mode>] [--saepwid=<SAE pass>] [--auth=<threshold>]
  Configure Wifi (changes are applied after reboot)
    -r, --read  Read current configuration from storage (no other argument required)
  -d, --delete  Delete current configuration in storage (no other argument required)
  --ssid=<SSID>  Wifi SSID
  --pwd=<password>  Wifi password
  --saemode=<SAE mode>  Integer value: 1 = HUNT AND PECK, 2 = H2E, 3 = BOTH
  --saepwid=<SAE pass>  SAE password identifier
  --auth=<threshold>  Authentication threshold: OPEN, WEP, WPA-PSK, WPA/WPA2-PSK, WPA2-PSK, WAPI-PSK, WPA2/WPA3-PSK, WPA3-PSK
```

### Configure network
```
config_network  [-rd] [--hostname=<hostname>] [--dhcp=<dhcp>] [--ip=<address>] [--mask=<netmask>] [--gateway=<gateway>] [--dns1=<DNS1 address>] [--dns2=<DNS2 address>] [--ntp=<NTP address>]
  Configure Network (changes are applied after reboot)
    -r, --read  Read current configuration from storage (no other argument required)
  -d, --delete  Delete current configuration in storage (no other argument required)
  --hostname=<hostname>  ESP32 hostname
  --dhcp=<dhcp>  1 to enabled DHCP, 0 to disable (static IP)
  --ip=<address>  ESP32 IPv4 address for static configuration
  --mask=<netmask>  Network mask for static configuration
  --gateway=<gateway>  Gateway IPv4 address for static configuration
  --dns1=<DNS1 address>  Main DNS server address for static configuration
  --dns2=<DNS2 address>  Backup DNS server address for static configuration
  --ntp=<NTP address>  NTP server address (eg pool.ntp.org)
```

### Configure MQTT client
```
config_mqtt  [-rd] [--state=<state>] [--addr=<address>] [--port=<port>] [--user=<username>] [--pass=<password>] [--tls=<tls_state>] [--cert=<certificate>] [--disc_id=<discovery_id>] [--topic=<topic_prefix>] [--discovery=<discovery_prefix>]
  Configure MQTT (changes are applied after reboot)
    -r, --read  Read current configuration from storage (no other argument required)
  -d, --delete  Delete current configuration in storage (no other argument required)
  --state=<state>  1 to enable MQTT client, 0 to disable
  --addr=<address>  Broker address to connect to
  --port=<port>  Broker port to connect to
  --user=<username>  Client username when connecting to MQTT broker
  --pass=<password>  Client password when connecting to MQTT broker
  --tls=<tls_state>  1 to enable TLS connection to MQTT broker, 0 to disable
  --cert=<certificate>  MQTT broker certificate (content of .pem file without --- BEGIN CERTIFICATE --- and ---END CERTIFICATE ---)
  --disc_id=<discovery_id>  ID and Name to use in discovery message
  --topic=<topic_prefix>  Prefix added before all MQTT topics except discovery
  --discovery=<discovery_prefix>  Prefix added before discovery topic. Discovery topic will be <discovery_prefix>/config
```

### Configure Syslog client
```
config_syslog  [-rd] [--enable=<0|1>] [--server=<host>] [--port=<port>] [--facility=<0-23>] [--level=<0-7>]
  Configure remote UDP syslog (RFC 3164)
    -r, --read  Read current syslog configuration
  -d, --delete  Delete syslog configuration (restore defaults)
  --enable=<0|1>  1 to enable syslog, 0 to disable
  --server=<host>  Syslog server hostname or IP
  --port=<port>  UDP port (default 514)
  --facility=<0-23>  RFC 3164 facility number
  --level=<0-7>  Minimum severity: 3=error 4=warn 6=info 7=debug
```

## Diagral related commands

### Diagral configuration
```
diagral_config  [-rd] [--logging=<state>] [--passive=<state>] [--checkpin=<state>]
  Configure Diagral controller layer
    -r, --read  Read current configuration from storage (no other argument required)
  -d, --delete  Delete current configuration in storage (no other argument required)
  --logging=<state>  1 to enable logging in Diagral controller layer, 0 to disable
  --passive=<state>  1 to enable passive state in Diagral controller layer, 0 to disable
  --checkpin=<state>  1 to enable PIN code check from MQTT
```

### "Get state" action
```
diagral_get_state 
  Get current state from Diagral system
```

### "Check PIN" action
```
diagral_checkpin  <pin code>
  Check a PIN code in Diagral system
    <pin code>  PIN code, 4 to 6 digits
```

### "Arm all zones" action
```
diagral_arm_all 
  Arm all zones in Diagral system
```

### "Arm specified zones" action
```
diagral_arm_zones  <zones>
  Arm specified zones in Diagral system
       <zones>  Specify the zone(s) to arm as a bit field (1 for zone 1, 2 for zone 2, 4 for zone 3, 8 for zone 4, 3 for zones 1 and 2, ...)
```

### "Arm Home" action
```
diagral_arm_home 
  Arm 'Home presence' in Diagral system
```

### "Disarm all zones" action
```
diagral_disarm_all 
  Disarm all zones in Diagral system
```

### "Disarm specified zones" action
```
diagral_disarm_zones  <zones>
  Disarm specified zones in Diagral system
       <zones>  Specify the zone(s) to disarm as a bit field (1 for zone 1, 2 for zone 2, 4 for zone 3, 8 for zone 4, 3 for zones 1 and 2, ...)
```

### "Send raw command" action
```
diagral_sendraw  <raw frame>
  Send an Digral frame from given string representation, waits for ACK.
   <raw frame>  String representation of the DiagralFrame, from Identifier byte to last byte of data (without Length, counter and CRC)
```

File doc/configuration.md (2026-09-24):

# Project configuration
The configuration permits to define severals parameters to customize the behavior of the ESP32.
The configuration can be done using several ways:
- Before building the firmware: the default configuration stored in firmware binary
- After building the firmware, while ESP32 is running: configuration is store in NVS partition in Flash and always overrides default configuration.
> [!TIP]
> If you change the default configuration and see no change after loading the firmware, it's probably because you have custom value stored in NVS partition that overrides the default value. You can decide to change directly the value in NVS or delete parameters in NVS to use default values. You can also use ESP-IDF tools to erase the NVS partition in Flash (address 0x370000 and size 0x4000, see [partition.csv](../partitions.csv))

## Ways to configure the project

### Before building the firmware
As previously said, you can choose default values before building the firmware:
- In VSCode: use the ESP-IDF addon by clicking on "SDK Configuration Editor (menuconfig)". Then go to "Diagral UART Project Configuration" section.
- Using a terminal: execute command 'idf.py menuconfig' (see ESP-IDF documentation)
> [!NOTE]
> Some parameters can be defined only before building the firmware, especially parameters related to hardware configuration.
Most of the parameters have a description to help you to choose the value.

#### Main parameters
This section permits to configure:
- Default value for password used to protect command line access
- OTA update using only HTTPS (secure update from known server)
- Wifi or Ethernet connectivity
- DHCP or static IPv4
- ESP32 hostname on your network
- NTP server to use to synchronize time on ESP32

#### Static IP configuration parameters
This section permits to configure:
- IPv4 address for the ESP32
- Network mask
- Gateway address
- Main DNS server address
- Backup DNS server address

#### Wifi configuration parameters
This section permits to configure:
- Wifi SSID
- Wifi password / key
- WPA3 SAE mode (if using WPA3)
- Password identifier (if using SAE H2E)
- WiFi authentication mode threshold: set it directly to the best value supported by your Wifi access point!

#### Ethernet configuration parameters
If you choose Ethernet connectivity in the main parameters, this section permits to configure parameters related to W5500 module:
- SPI host to use (depending on your ESP32 chip, you can have HOST2 and HOST3 or only HOST2)
- SPI clock speed (MHz)
- GPIO to use for:
  - SPI CS
  - Interrupt
  - PHY Reset

#### Diagral configuration parameters
This section permits to configure:
- Enable logging in Diagral UART layer (all logs from the Diagral UART layer will be sent to command line interface, and MQTT log topic if MQTT is configured)
- Passive mode only (ESP32 is not allowed to emit)
- PIN code
- GPIO connected to Diagral system and used for:
  - TX (Pin 8 on Diagral board 20 pins connector)
  - RX (Pin 10 on Diagral board 20 pins connector)
  - TX Flag (Pin 9 on Diagral board 20 pins connector)

#### MQTT configuration parameters
This section permits to configure:
- MQTT client activation
- MQTT Broker address
- MQTT Broker port
- MQTT Client ID (must be unique in your broker)
- MQTT Client username and password to authenticate when connecting to the broker
- TLS protection and certificate when connecting to the broker
- MQTT prefix to use for all topics (except discovery)
- MQTT prefix to use for discovery topic

#### Hardware configuration parameters
This section permits to configure GPIO for SPI HOST2 and/or HOST3 if available and used by Ethernet module:
- SPI SCK
- SPI MOSI
- SPI MISO

### After building the firmware
Most of the parameters, excluding hardware configuration, can be changes using the command line / console interface available on serial interface (or USB to serial interface). Check these commands:
- config_network for configuration related to IPv4 / DHCP / DNS / NTP
- config_wifi for configuration related to Wifi
- config_mqtt for configuration related to MQTT
- diagral_config for configuration related to Diagral
> [!IMPORTANT]
> By default the command line interface is password protected. It strongly recommanded to change the default password (before building the firmware or after loading the firmware in ESP32 chip).
In addition, a few parameters can be changed using MQTT topics.

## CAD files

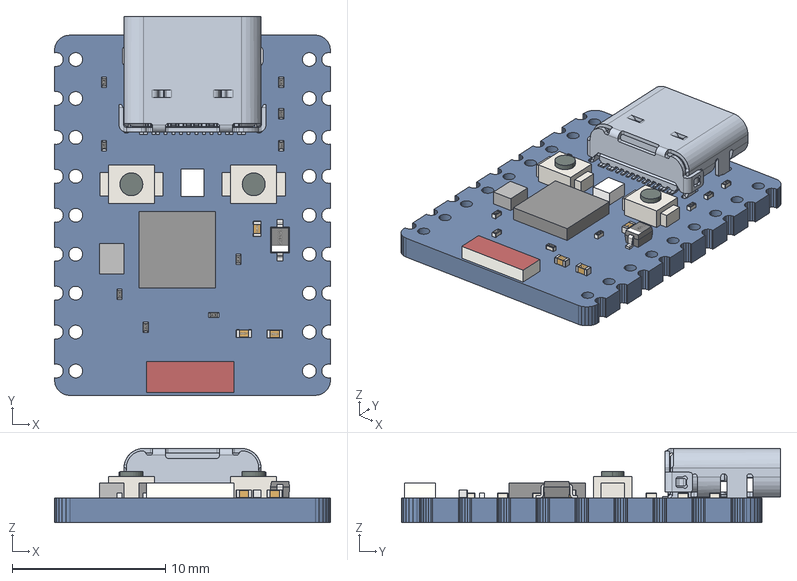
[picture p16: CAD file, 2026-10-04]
kicad/Waveshare-ESP32-C6-Zero.step
18.0 x 24.7 x 4.85 mm
BOARD
USER_LIBRARY-RES_0603-0201_1 x 9
USER_LIBRARY-RES_0603-0201_2 x 9
USER_LIBRARY-RES_0603-0201_3 x 9
USER_LIBRARY-RES_0603-0201_4 x 9
EXTRUDED-29178
2_A x 13
EXTRUDED-51780
EXTRUDED-52493 x 2
SOD323
3_1_A x 3
CORE
CA-C03

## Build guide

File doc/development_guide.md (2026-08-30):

# Development guidelines

## Project structure

Project is organized in folders:
- root folder contains readme, licence, project default configuration and flash partitioning
- main/ contains main components and project configuration
- doc/ contains documentation (in addition to readme)
- config/ contains classes related to configuration management
- helpers/ contains classes and functions related to specific features like command line management, configuration and devices storage, MQTT frontend, network management.
- diagral/ contains main implementation of the Diagral protocol over UART

> [!NOTE]
> If you want to reuse Diagral protocol management with a different frontend, you can directly use diagral/ in your project. Please add a link to my project.

## Project documentation

Most of the classes, methods and members are directly described in source code using doxygen.

## External components

Most of the source code not directly related to Diagral has been written based on examples from ESP-IDF SDK: NVS and configuration, Ethernet and Wifi, MQTT, command line tools...  
You can also read ESP-IDF SDK documentation and examples documentation to learn more about these features.

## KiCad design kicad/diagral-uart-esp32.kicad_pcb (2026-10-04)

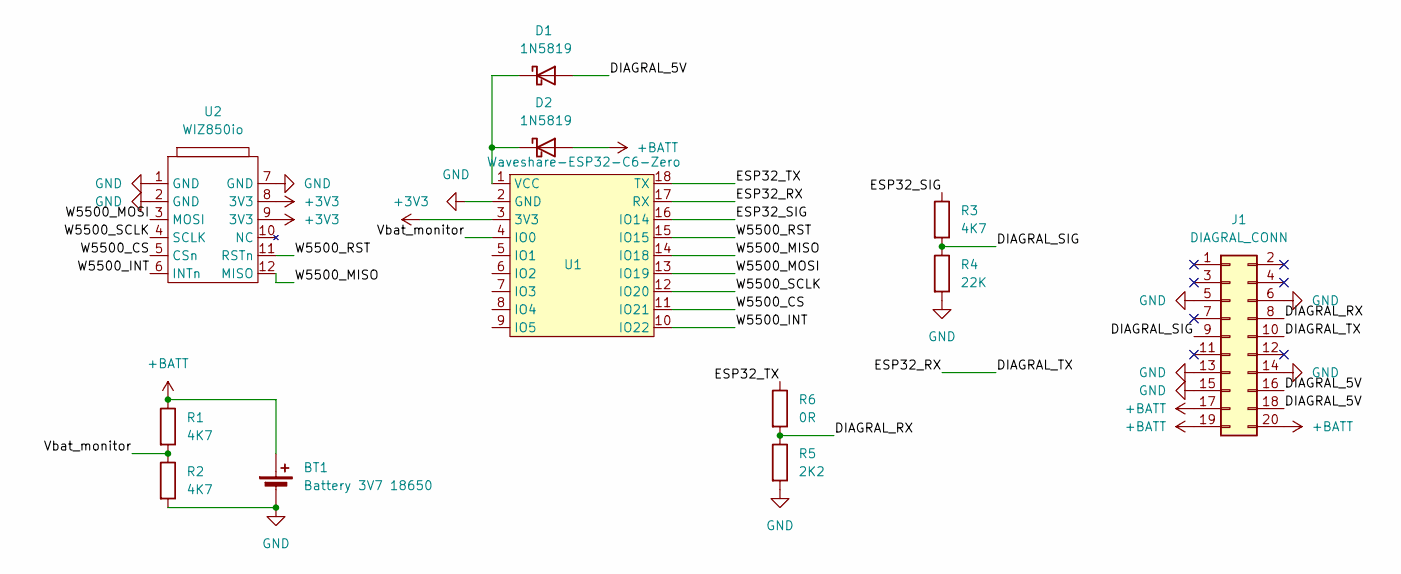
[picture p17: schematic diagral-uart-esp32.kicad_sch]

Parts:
BT1: Battery 3V7 18650; JST_XH_B2B-XH-A_1x02_P2.50mm_Vertical
D1, D2: 1N5819; D_DO-41_SOD81_P10.16mm_Horizontal
J1: DIAGRAL_CONN; PinHeader_2x10_P2.54mm_Vertical
R1, R2, R3: 4K7; R_Axial_DIN0207_L6.3mm_D2.5mm_P10.16mm_Horizontal
R4: 22K; R_Axial_DIN0207_L6.3mm_D2.5mm_P10.16mm_Horizontal
R5: 2K2; R_Axial_DIN0207_L6.3mm_D2.5mm_P10.16mm_Horizontal
R6: 0R; R_Axial_DIN0207_L6.3mm_D2.5mm_P10.16mm_Horizontal
U1: Waveshare-ESP32-C6-Zero
U2: WIZ850io

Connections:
+3V3: U1.3 (3V3), U2.8 (3V3), U2.9 (3V3)
+BATT: BT1.1 (+), D2.2 (A), J1.17, J1.19, J1.20, R1.1
/DIAGRAL_5V: D1.2 (A), J1.16, J1.18
/DIAGRAL_RX: J1.8, R5.1, R6.2
/DIAGRAL_SIG: J1.9, R3.2, R4.1
/DIAGRAL_TX: J1.10, U1.17 (RX)
/ESP32_SIG: R3.1, U1.16 (IO14)
/ESP32_TX: R6.1, U1.18 (TX)
/Vbat_monitor: R1.2, R2.1, U1.4 (IO0)
/W5500_CS: U1.11 (IO21), U2.5 (CSn)
/W5500_INT: U1.10 (IO22), U2.6 (INTn)
/W5500_MISO: U1.14 (IO18), U2.12 (MISO)
/W5500_MOSI: U1.13 (IO19), U2.3 (MOSI)
/W5500_RST: U1.15 (IO15), U2.11 (RSTn)
/W5500_SCLK: U1.12 (IO20), U2.4 (SCLK)
GND: BT1.2 (-), J1.5, J1.6, J1.13, J1.14, J1.15, R2.2, R4.2, R5.2, U1.2 (GND), U2.1 (GND), U2.2 (GND), U2.7 (GND)
unnamed: D1.1 (K), D2.1 (K), U1.1 (VCC)

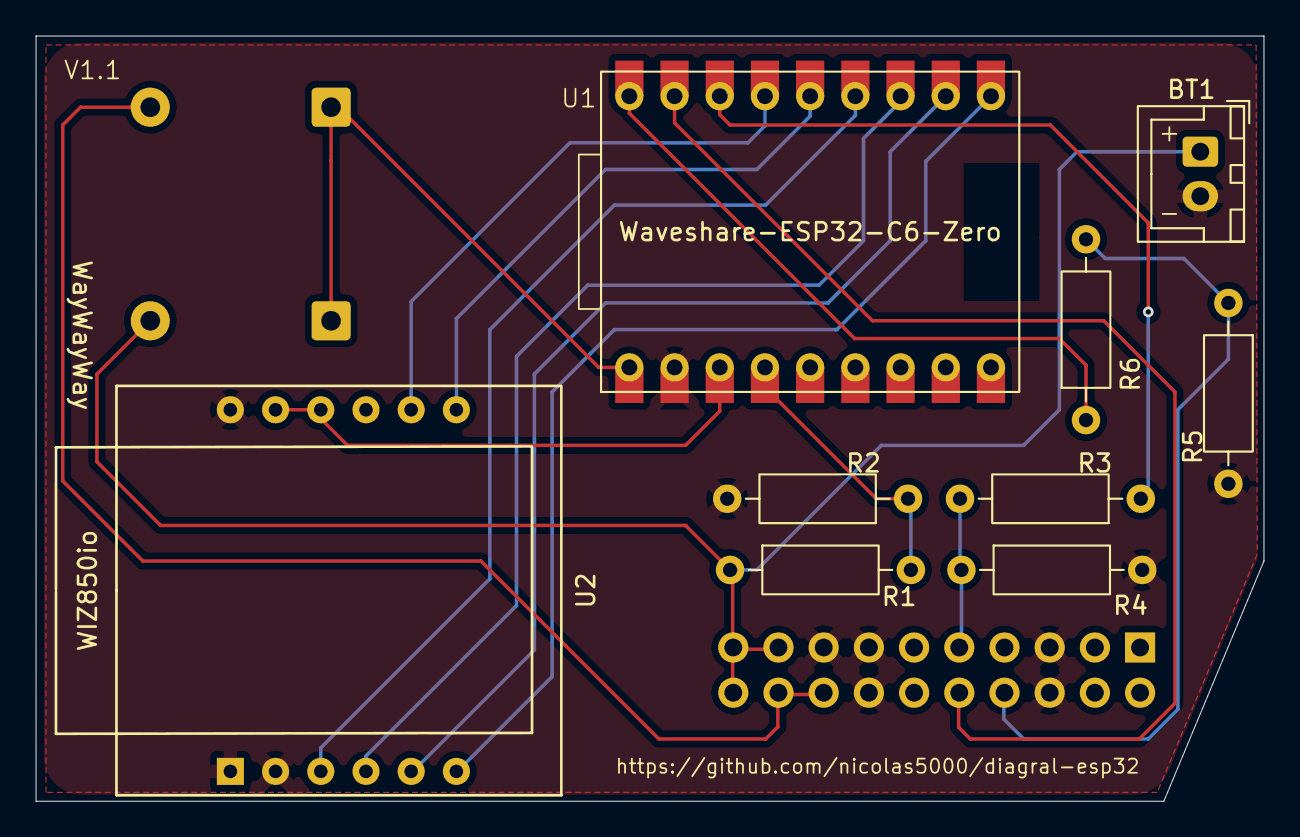
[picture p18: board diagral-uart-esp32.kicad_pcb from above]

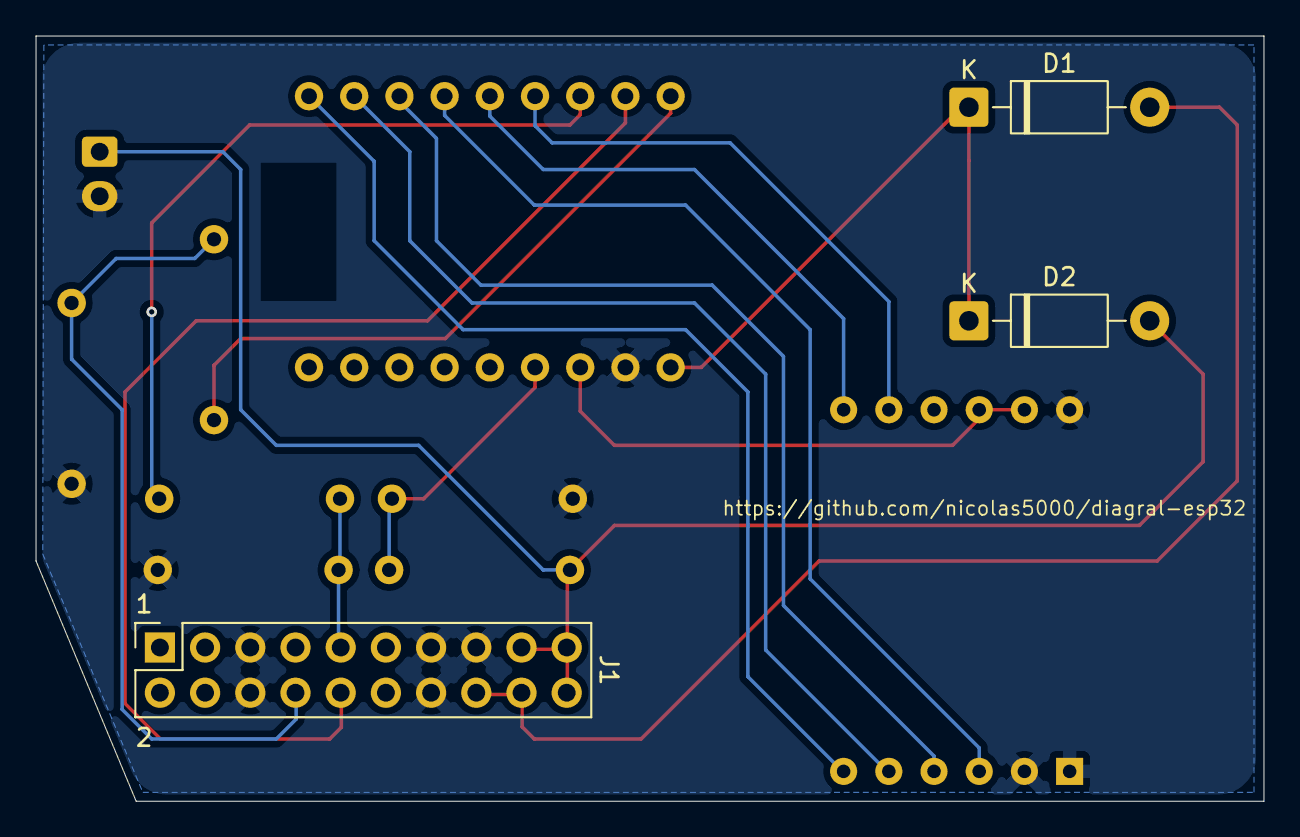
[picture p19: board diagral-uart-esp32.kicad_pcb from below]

Board: 2 copper layers, 69.0 x 43.0 mm, 12 parts (3 on the bottom side), 17 nets.

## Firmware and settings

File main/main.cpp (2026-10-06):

#include <stdio.h>
#include <string.h>

#include "HardwareConfig.hpp"
#include "DiagralManager.hpp"
#include "CmdLineManagement.hpp"

#include "esp_log.h"
#include "sdkconfig.h"
#include "esp_console.h"

extern "C" void app_main(void)
{
    // Initialize Hardware: NVS, LittleFS, GPIO ISR, SPI bus
    esp_err_t err = Config::InitHardware();
    ESP_ERROR_CHECK(err);

    // Initialize Manager
    Diagral::DiagralManager diagralManager = Diagral::DiagralManager();

    vTaskDelay(pdMS_TO_TICKS(10000));
    // Initialize commands line tools
    init_cmdline(&diagralManager);

    while (true)
        vTaskDelay(pdMS_TO_TICKS(60000));
}

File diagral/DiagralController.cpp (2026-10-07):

#include "DiagralController.hpp"
#include "DiagralCommands.hpp"
#include "esp_task_wdt.h"
#include "esp_timer.h"
#include "freertos/task.h"
#include "driver/uart.h"
#include "driver/gpio.h"
#include <esp_adc/adc_oneshot.h>
#include "esp_adc/adc_cali.h"
#include "esp_adc/adc_cali_scheme.h"

#include <stdio.h>
#include <time.h>
#include <algorithm>
#include "esp_log.h"
#include <ios>
#include <sstream>
#include <map>
#include <list>
#include <iostream>
#include <iomanip>
#include <format>
#include <mutex>

static const char *TAG = "diagral-ctrl";

constexpr int DIAGRAL_UART_BAUDRATE = 115200; // UART baudrate
constexpr int DIAGRAL_UART_RXBUFF_SIZE = 256; // Buffer size for RX on UART

constexpr uint32_t UART_WAIT_FIRSTBYTE_TIME = 780 / portTICK_PERIOD_MS;    // 780 ms max time to wait to receive first byte
constexpr uint32_t UART_WAIT_COMPLETEFRAME_TIME = 20 / portTICK_PERIOD_MS; // 20 ms max time to wait to receive complete frame once first byte is received
constexpr uint32_t UART_WAIT_FOR_ACK = 250 / portTICK_PERIOD_MS;           // 250 ms max time to wait for ACK
constexpr uint32_t UART_WAIT_AFTER_ACK = 5 / portTICK_PERIOD_MS;           // 5 ms max time to wait after sending ACK
constexpr uint32_t UART_WAIT_BEFORE_SEND = 4 / portTICK_PERIOD_MS;         // 4 ms time to wait after setting TX signal and before sending frame
constexpr uint32_t UART_RX_CHECK_INTERVAL = 20;                            // Time between 2 'Rx' check.

constexpr TickType_t MUTEX_MAX_WAIT_TICKS = 30000 * portTICK_PERIOD_MS; // 30 seconds
constexpr TickType_t UPDATE_STATE_WAKEUP_INTERVAL_MS = 5000;            // 5 seconds

constexpr UBaseType_t RX_FRAME_PROCESSING_PRIORITY = tskIDLE_PRIORITY + 6; // priority higher than IDLE, to perform RX frame work
constexpr UBaseType_t DEVICE_STATE_UPDATE_PRIORITY = tskIDLE_PRIORITY + 4; // priority higher than IDLE but less than RX processing, to launch status update
constexpr UBaseType_t DEVICE_STATE_CALLBACK_PRIORITY = tskIDLE_PRIORITY;   // priority same as IDLE (low priority)
constexpr UBaseType_t LOG_CALLBACK_PRIORITY = tskIDLE_PRIORITY;            // priority same as IDLE (low priority)

constexpr int64_t STATE_UPDATE_MAX_TIME_US = 3600000000; // 1 hour to next status update if nothing happens before
constexpr int64_t STATE_UPDATE_NEXT_TRY_US = 60000000;   // 60 seconds to wait if Get State failed

constexpr TickType_t UPDATE_VOLTAGE_INTERVAL_MS = 300000; // 300 seconds = 5 minutes

constexpr size_t LOG_MESSAGE_MAXSIZE = 256;

#define DIAG_LOGE(a, ...)                                                 \
  do                                                                      \
  {                                                                       \
    DiagralLog(ESP_LOG_ERROR, std::format(a __VA_OPT__(, ) __VA_ARGS__)); \
  } while (0)
#define DIAG_LOGI(a, ...)                                                \
  do                                                                     \
  {                                                                      \
    DiagralLog(ESP_LOG_INFO, std::format(a __VA_OPT__(, ) __VA_ARGS__)); \
  } while (0)

namespace Diagral
{
  static uart_port_t sUartPort = uart_port_t::UART_NUM_0; // UART port to use to communicate with Diagral system
  static uint8_t sFrameCounter = 0;                       // Frame counter for frames sent to Diagral system
  static QueueHandle_t sLogQueue = NULL;                  // Contains logs (LogQueueItem) to be sent to log callback
  static QueueHandle_t sDeviceStateQueue = NULL;          // Contains device state (DiagralDeviceState items) to be sent to status callback
  static DiagralDeviceState sDeviceState;                 // Current device state
  static uint64_t sNextStateUpdateTimestamp;              // Next time Device state should be updated
  static LoggerCallback sLoggerCallback;                  // Callback to send logs to
  static UpdatedDeviceCallback sDeviceStatusCallback;     // Callback to send device status updates to
  static BatteryMonitorConfig sBatteryConfig;             // Structure to store battery config to use in the update thread

  struct LogQueueItem
  {
    char log[LOG_MESSAGE_MAXSIZE];
    uint32_t timestamp;
    esp_log_level_t log_level;
  };

  /// @brief Generate a log from given string and level, and send it to registered callback
  /// @param log_level Log level
  /// @param log Log string
  static void DiagralLog(esp_log_level_t log_level, std::string log)
  {
    LogQueueItem logItem;
    memset(&logItem, 0, sizeof(LogQueueItem));
    logItem.log_level = log_level;
    logItem.timestamp = esp_log_timestamp();
    size_t messageSize = log.length() < LOG_MESSAGE_MAXSIZE ? log.length() : LOG_MESSAGE_MAXSIZE - 1;
    memcpy(logItem.log, log.c_str(), messageSize);
    if (!xQueueSendToBack(sLogQueue, &logItem, 0))
    {
      ESP_LOGE(TAG, "DiagralLog can't add log to queue!");
    }
  }

  /// @brief Convert a buffer to a HEX string representation
  /// (0x12 0x34 0xab -> "1234AB")
  /// @param len length of the input buffer
  /// @param buffer Buffer containing the bytes
  /// @return The string containing the HEX representation of the input buffer
  static std::string buffToHexString(uint8_t len, const uint8_t buffer[])
  {
    std::ostringstream convert;
    for (int a = 0; a < len; a++)
    {
      convert << std::format("{:02X}", buffer[a]);
    }
    return convert.str();
  }

  /// @brief Convert an HEX string to a byte buffer
  /// @param hex HEX string (eg "1234AB")
  /// @param buffer Buffer that will receive the string conversion (eg, will be 0x12 0x34 0xab)
  /// @param len Length of the allocated buffer, needs to be at least HEX string length / 2
  static void HexStringToBuff(const std::string &hex, uint8_t buffer[], uint8_t len)
  {
    if (len < hex.length() / 2)
    {
      DIAG_LOGE("HexStringToBuff: buffer is too short! ({}, need {})", len, hex.length() / 2);
      return;
    }
    std::istringstream ss(hex);
    std::string s2;
    unsigned int i = 0;
    while ((ss >> std::setw(2) >> s2))
    {
      buffer[i / 2] = (uint8_t)strtol(s2.c_str(), nullptr, 16);
      i += 2;
    }
  }
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

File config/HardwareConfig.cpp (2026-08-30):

#include "HardwareConfig.hpp"
#include "NvsHelpers.hpp"

#include "sdkconfig.h"
#include "driver/gpio.h"
#include "esp_log.h"

static const char *TAG = "HardwareConfig";

constexpr int8_t ESP_INTR_FLAG_DEFAULT = 0;

using namespace Helpers;

namespace Config
{
#if defined(CONFIG_IOHOMECONTROL_SX1276_SPI_HOST2) || defined(CONFIG_ETHERNET_SPI_HOST2)
    /// @brief Initialize SPI_HOST2 from configuration
    /// @return ESP_OK if no error
    static esp_err_t InitSPIHost2()
    {
        // Init SPI bus
        spi_bus_config_t bus = {};
        bus.mosi_io_num = CONFIG_SPI_HOST2_MOSI;
        bus.miso_io_num = CONFIG_SPI_HOST2_MISO;
        bus.sclk_io_num = CONFIG_SPI_HOST2_SCK;
        bus.quadwp_io_num = -1;
        bus.quadhd_io_num = -1;
        return spi_bus_initialize(SPI2_HOST, &bus, SPI_DMA_CH_AUTO);
    }
#endif

#if defined(CONFIG_IOHOMECONTROL_SX1276_SPI_HOST3) || defined(CONFIG_ETHERNET_SPI_HOST3)
    /// @brief Initialize SPI_HOST3 from configuration
    /// @return ESP_OK if no error
    static esp_err_t InitSPIHost3()
    {
        // Init SPI bus
        spi_bus_config_t bus = {};
        bus.mosi_io_num = CONFIG_SPI_HOST3_MOSI;
        bus.miso_io_num = CONFIG_SPI_HOST3_MISO;
        bus.sclk_io_num = CONFIG_SPI_HOST3_SCK;
        bus.quadwp_io_num = -1;
        bus.quadhd_io_num = -1;
        return spi_bus_initialize(SPI3_HOST, &bus, SPI_DMA_CH_AUTO);
    }
#endif

    esp_err_t InitHardware()
    {
        // Initialize NVS
        esp_err_t err = NvsHelpers::InitNvs();
        if (err != ESP_OK)
        {
            ESP_LOGE(TAG, "Failed to initialize NVS");
            return err;
        }

        // Install GPIO ISR service
        err = gpio_install_isr_service(ESP_INTR_FLAG_DEFAULT);
        if (err != ESP_OK)
        {
            ESP_LOGE(TAG, "Failed to install GPIO ISR service");
            return err;
        }

        // Init SPI bus
#if defined(CONFIG_ETHERNET_SPI_HOST2)
        // Init SPI_HOST2
        err = InitSPIHost2();
        if (err != ESP_OK)
        {
            ESP_LOGE(TAG, "Failed to initialize SPI_HOST2");
            return err;
        }
#endif
#if defined(CONFIG_ETHERNET_SPI_HOST3)
        // Init SPI_HOST3
        err = InitSPIHost3();
        if (err != ESP_OK)
        {
            ESP_LOGE(TAG, "Failed to initialize SPI_HOST3");
            return err;
        }
#endif
        return err;
    }

#ifdef CONFIG_CONNECTIVITY_CHOICE_ETH
    spi_host_device_t GetEthernetSpiHost()
    {
#ifdef CONFIG_ETHERNET_SPI_HOST2
    return SPI2_HOST;
#elifdef CONFIG_ETHERNET_SPI_HOST3
    return SPI3_HOST;
#endif
    }
#endif
}

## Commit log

2026-08-30 first version of the project for sharing
    [partitions.csv]
2026-09-13 fix management of errors returned by alarm system
    [DiagralController.cpp, DiagralManager.cpp]
2026-09-13 add battery low notification
2026-09-16 fix battery error values
2026-09-17 add error events for siren
    [DiagralController.cpp]
2026-09-26 change default device state to installation mode
2026-09-26 send I=07/J=B0/K=30 frames when mode changed to idle
2026-09-26 send I=07/J=B0/K=06 and I=07/J=43 frames when mode changed to idle
2026-09-26 send I=07/J=B0/K=0C frame when mode changed to idle
2026-09-30 fix Diagral config reading pin check parameter
2026-09-30 information about hardware and PCB, adding kicad project
    [diagral-uart-esp32.kicad_pcb, diagral-uart-esp32.kicad_sch]
2026-10-02 fix last_error for tamper from alarm system itself
    [DiagralController.cpp]
2026-10-04 add compatibility with Waveshare ESP32-C6 and Waveshare ESP32-S3 - update PCB to version 1.1
    [Waveshare-ESP32-C6-Zero.step, diagral-uart-esp32.kicad_pcb, diagral-uart-esp32.kicad_sch]
2026-10-05 update PCB_front.jpg with 1N5819 on PCB 1.0
2026-10-05 rename 'battery_low' to 'battery' as it can be any error related to battery
    [DiagralController.cpp]
2026-10-05 add errors related to Internet transmitter and Internet/data link
    [DiagralController.cpp]
2026-10-05 add error feedback when arming is cancelled due to open issue, tamper or transmitter error
    [DiagralController.cpp]
2026-11-04 Separate OTA configuration from update execution (#5)
    * Separate OTA configuration from update execution
    Persist the firmware URL in a dedicated NVS namespace, add an explicit MQTT update button and status sensor, and run downloads in a guarded FreeRTOS task. Reject retained or fragmented OTA commands and document the new workflow.
    * Restrict the HTTPS OTA helper to an explicit firmware endpoint
    Keep positional arguments, use loopback by default with explicit LAN binding and optional CIDR filtering, resolve paths without chdir, and require existing certificates without generating or exposing keys. Add HTTPS transfer and access-control tests.
